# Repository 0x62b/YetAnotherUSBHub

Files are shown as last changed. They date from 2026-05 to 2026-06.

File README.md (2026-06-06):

# YetAnotherUSBHub
A 4-port low cost USB 2.0 hub with upstream USB-C and downstream USB-A x2, USB-C, and microSD.
wip onshape: https://cad.onshape.com/documents/d3076bcf5bdf960a68612e95/w/1076ab7133259d721c6eb065/e/0b541aa8461793eb55190b47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

## Repo Structure
`cad`: CAD files\
`pcb`: The KiCad PCB design files, and gerbers in `pcb/production`\
`bom.csv`: The BOM needed to assemble the PCB\

## BOM
|Item |Unit Price (AUD)|Quantity|Extended Price (AUD)|Extended Price (USD) |Notes |Link |
|---|---|---|---|---|---|---|
|100nF 0402 capacitor |0 |2 |0 |0 |Owned |https://www.lcsc.com/product-detail/C60474.html |
|10uF 0402 capacitor |0 |7 |0 |0 |Owned |https://www.lcsc.com/product-detail/C315248.html |
|onsemi NSR0320MW2T1G |0.16 |10 |1.6 |1.18 |MOQ 10 |https://www.lcsc.com/product-detail/C48192.html |
|Green 0402 LED |0 |1 |0 |0 |Owned |https://www.lcsc.com/product-detail/C598352.html |
|Molex 67643-2911 |1.34 |2 |2.68 |1.92 |N/A |https://www.lcsc.com/product-detail/C293351.html |
|Molex 104031-0811 |1.05 |1 |1.05 |0.75 |N/A |https://www.lcsc.com/product-detail/C585350.html |
|Korean Hroparts Elec TYPE-C-31-M-12|0 |2 |0 |0 |Owned |https://www.lcsc.com/product-detail/C165948.html |
|1K 0402 resistor |0 |1 |0 |0 |Owned |https://www.lcsc.com/product-detail/C106235.html |
|5.1K 0402 resistor |0 |2 |0 |0 |Owned |https://www.lcsc.com/product-detail/C105872.html |
|56K 0402 resistor |0 |2 |0 |0 |Owned |https://www.lcsc.com/product-detail/C114756.html |
|CoreChips SL2.1A |1.65 |1 |1.65 |1.18 |N/A |https://www.lcsc.com/product-detail/C192893.html |
|GENESYS GL823K-HCY04 |0.64 |1 |0.64 |0.46 |N/A |https://www.lcsc.com/product-detail/C284879.html |
|TPD2E2U06DCK |0.21 |3 |1.05 |0.76 |MOQ 5 |https://www.lcsc.com/product-detail/C1855726.html |
|TPD6F003 |0.93 |1 |0.93 |0.67 |N/A |https://www.lcsc.com/product-detail/C2863873.html |
|2mm acrylic sheet |6.25 |1 |6.25 |4.53 |200x200x2mm|https://www.aliexpress.com/item/32817321651.html |
|PCB |- |5 |- |5.3 |N/A |https://jlcpcb.com |

## Cost
BOM (1 board + case): LCSC[6.92 USD + 3 USD handling + 9.38 USD shipping = 19.3 USD] + AliExpress[4.53 USD] = 23.83 USD\
PCB: 2 USD + 3.3 USD shipping = 5.3 USD\
Total: 29.13 USD (1 board + case)

## Assembly
Prerequisites: soldered PCB and printed case (PRINT THE CASE WITH +1-2% SCALE FOR TOLERANCES)

1. Mark out the dimensions of the acrylic window and use a scoring tool to cut it
2. From the sides, glue the acrylic window into the top case
3. Wait for glue to set
4. Place completed PCB into bottom case (optionally, affix it with double sided tape, but it should be held in place by friction anyway
5. Glue the top half onto bottom half (I tried, with this kind of size its not very feasible to use screws or anything)

## Images
### Schematic


### PCB layout


### PCB render


### Full render

The model may appear not to fit, but this was due to the export being messed up. it fits fine according to all my calculations and two braincells

### Zine


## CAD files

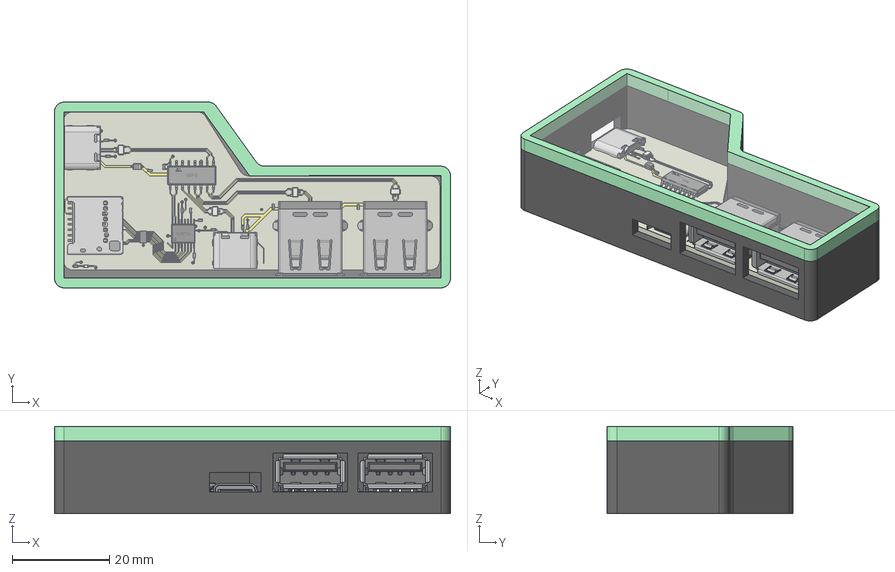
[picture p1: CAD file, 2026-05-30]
cad/usb hub full assembly.step
81.6 x 38.3 x 18.0 mm

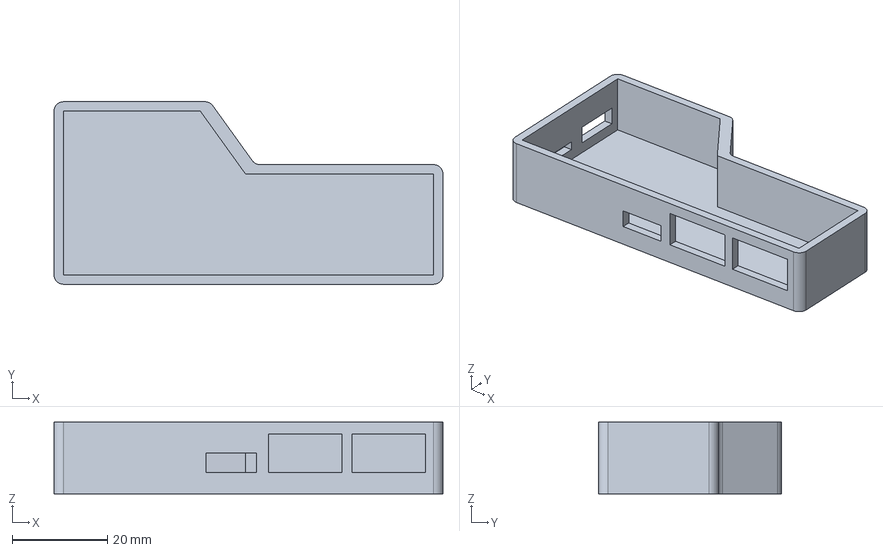
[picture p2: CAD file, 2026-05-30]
cad/usb hub bottom case.step
81.6 x 38.3 x 15.0 mm

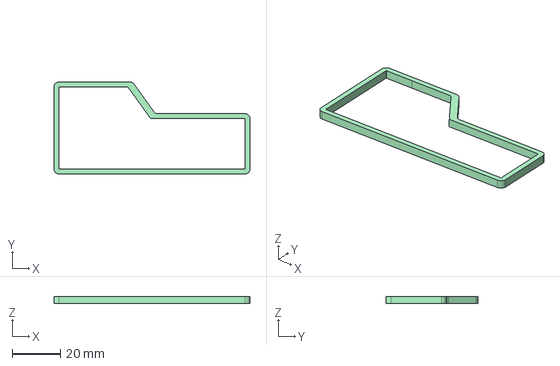
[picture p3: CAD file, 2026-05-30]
cad/usb hub top case.step
81.6 x 38.3 x 3.00 mm

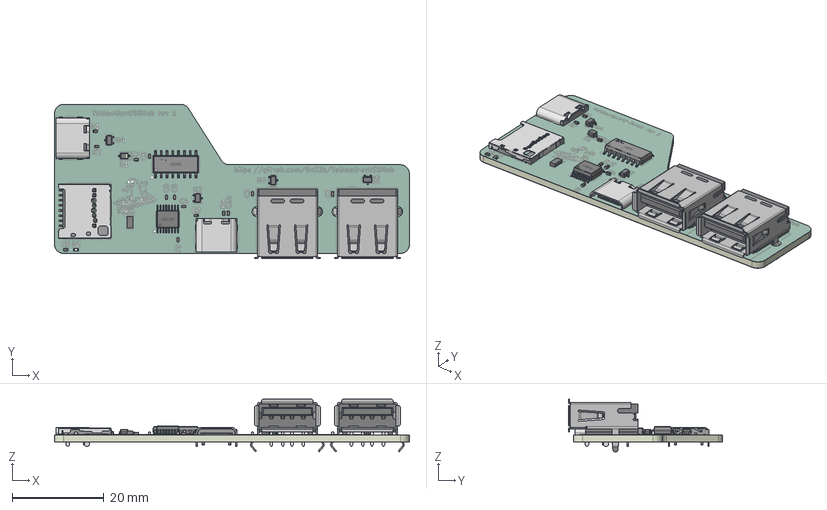
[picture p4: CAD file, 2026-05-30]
cad/board.step
77.6 x 33.7 x 11.5 mm
USB_A_Molex_67643_Horizontal x 2
SOT-323_SC-70 x 4
R_0402_1005Metric x 5
C_0402_1005Metric x 9
SOP-16_L9.9-W3.9-H1.5-LS6.0-P1.27
LED_0402_1005Metric
USB-C-SMD_TYPE-C-6PIN-2MD-073 x 2
D_SOD-323
SSOP-16_L4.9-W3.9-H1.75-LS6.0_P0.64
WSON_12_1EP_135x25mm_P04mm_EP04x2mm
SIM-SMD_8P-1040310811
YetAnotherUSBHub_copper
YetAnotherUSBHub_via
YetAnotherUSBHub_silkscreen
YetAnotherUSBHub_soldermask x 2
YetAnotherUSBHub_PCB

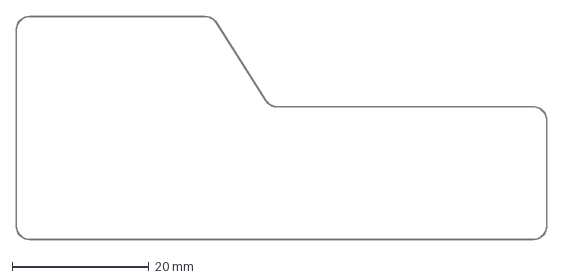
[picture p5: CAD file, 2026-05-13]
cad/YetAnotherUSBHub-Edge_Cuts.dxf
77.7 x 32.7 mm

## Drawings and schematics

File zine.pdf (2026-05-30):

# Yet Another USB Hub

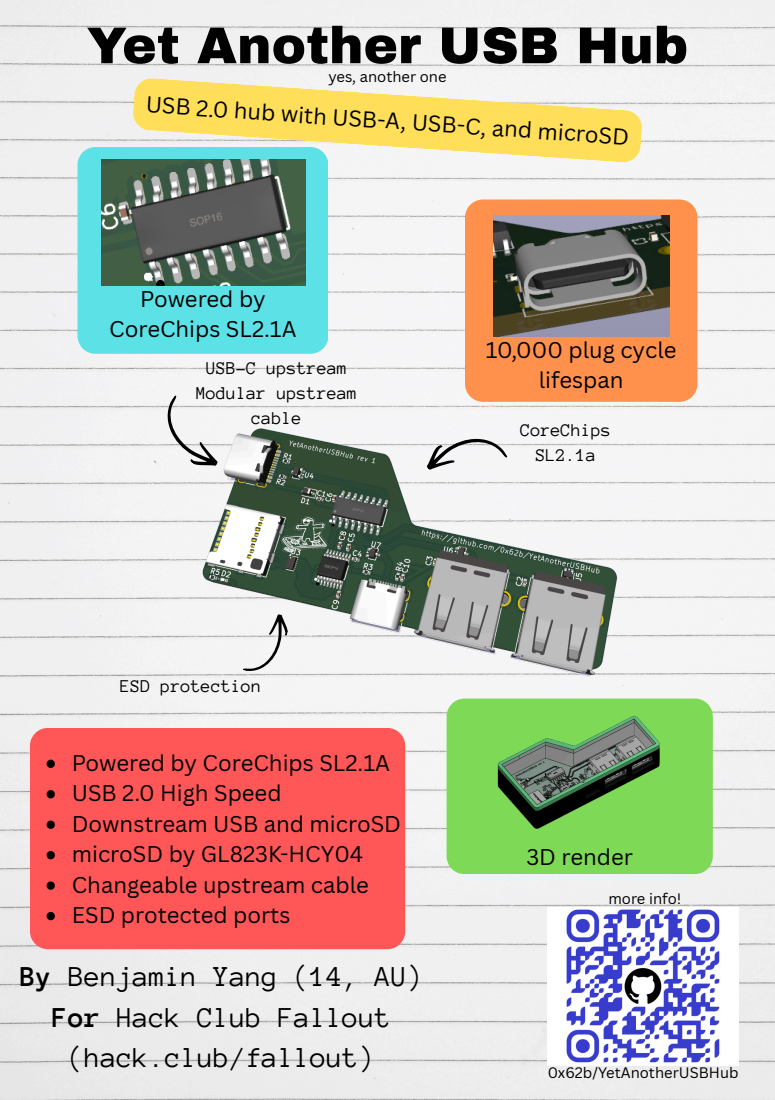
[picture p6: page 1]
Powered by CoreChips SL2.1A; 10,000 plug cycle lifespan; 3D render; USB-C upstream Modular upstream cable; ESD protection; CoreChips SL2.1a

yes, another one

USB 2.0 hub with USB-A, USB-C, and microSD

Powered by CoreChips SL2.1A
USB 2.0 High Speed
Downstream USB and microSD
microSD by GL823K-HCY04
Changeable upstream cable
ESD protected ports

0x62b/YetAnotherUSBHub more info!

By Benjamin Yang (14, AU)
For Hack Club Fallout
(hack.club/fallout)

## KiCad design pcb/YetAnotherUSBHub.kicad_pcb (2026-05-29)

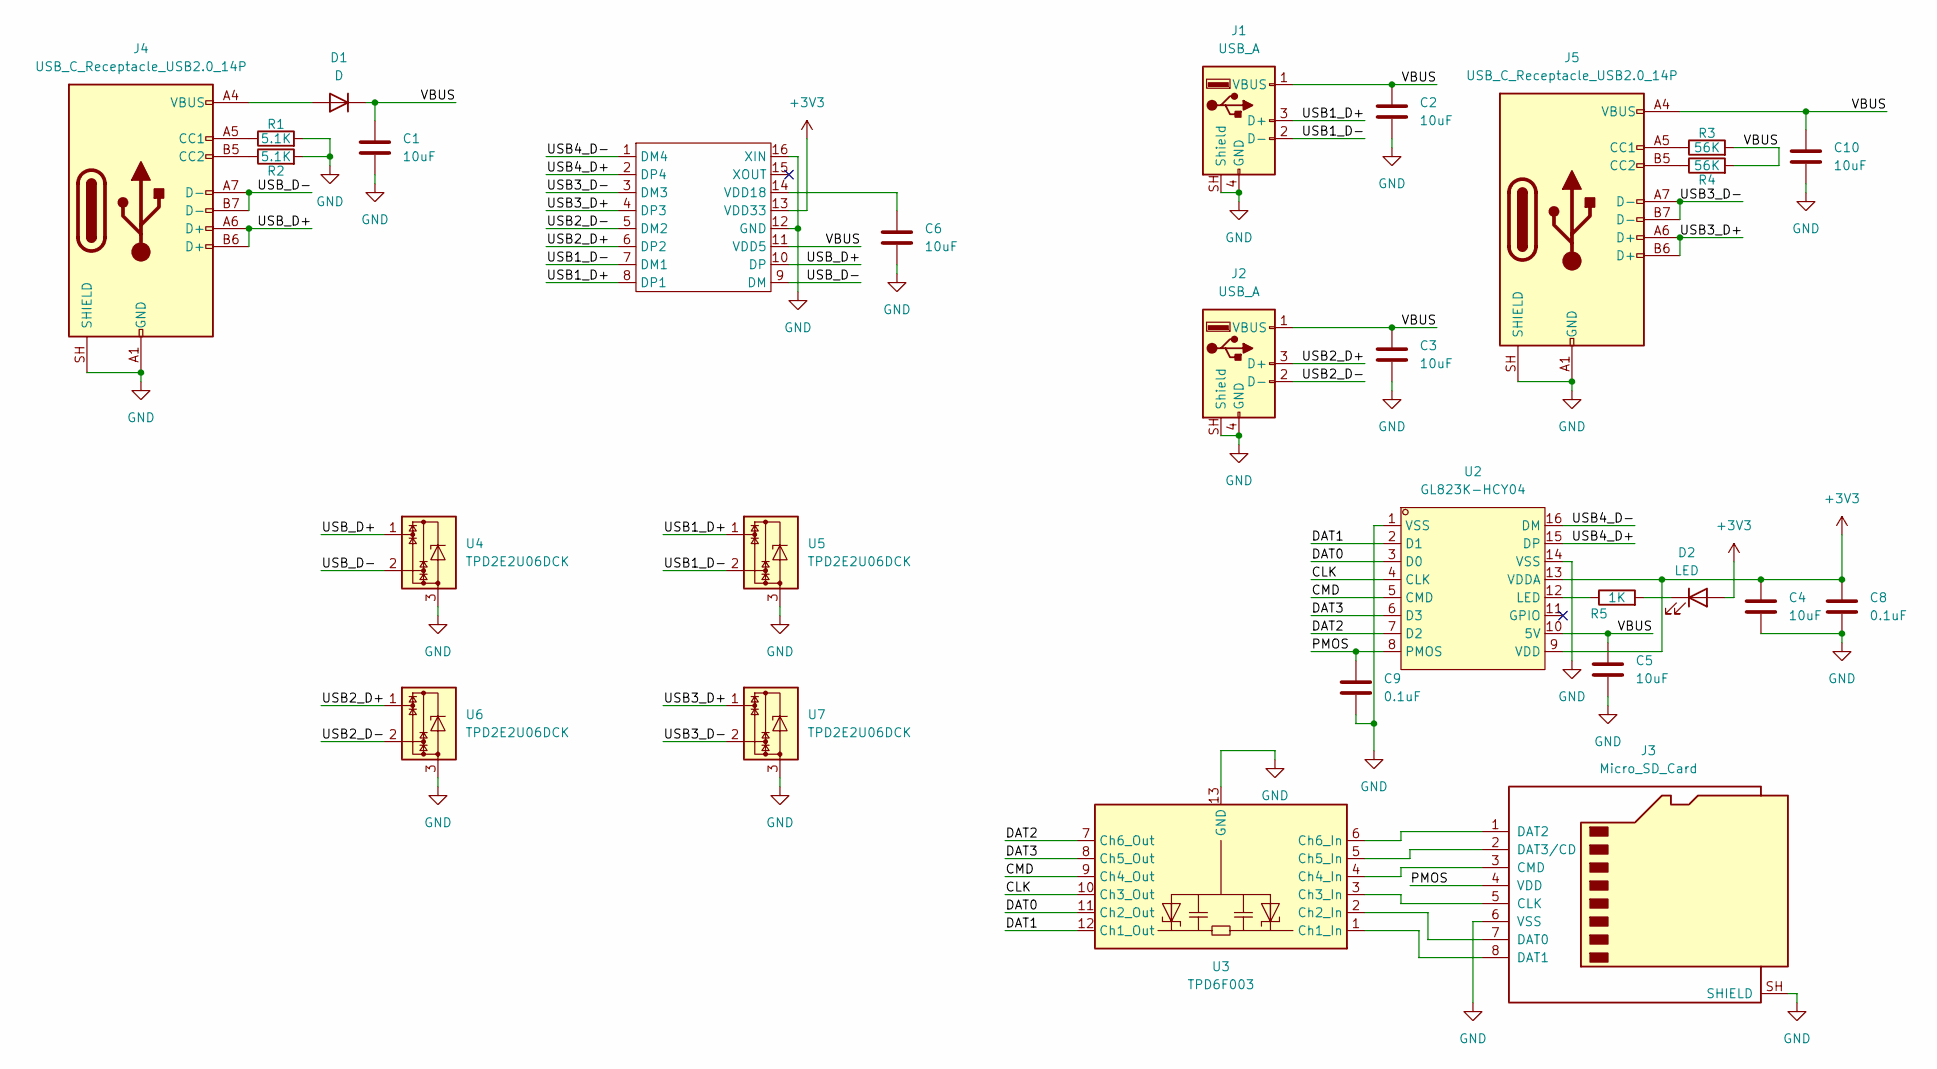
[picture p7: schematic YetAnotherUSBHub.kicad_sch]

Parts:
C1, C2, C3, C4, C5, C6, C10: 10uF; C_0402_1005Metric
C8, C9: 0.1uF; C_0402_1005Metric
D1: D; D_SOD-323
D2: LED; LED_0402_1005Metric
J1, J2: USB_A; USB_A_Molex_67643_Horizontal
J3: Micro_SD_Card; microSD_HC_Molex_104031-0811
J4, J5: USB_C_Receptacle_USB2.0_14P; USB_C_Receptacle_HRO_TYPE-C-31-M-12
R1, R2: 5.1K; R_0402_1005Metric
R3, R4: 56K; R_0402_1005Metric
R5: 1K; R_0402_1005Metric
U1: SOP-16_L10.0-W3.9-P1.27-LS6.0-BL
U2: GL823K-HCY04; SSOP-16_L4.9-W3.9-P0.64-LS6.0-BL; MPN GL823K-HCY04; LCSC Part C284879
U3: TPD6F003; Texas_R-PWSON-N12_EP0.4x2mm
U4, U5, U6, U7: TPD2E2U06DCK; SOT-323_SC-70

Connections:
+3V3: C4.1, C8.1, D2.2 (A), U1.13 (VDD33), U2.9 (VDD), U2.13 (VDDA)
/CLK: U2.4 (CLK), U3.10 (Ch3_Out)
/CMD: U2.5 (CMD), U3.9 (Ch4_Out)
/DAT0: U2.3 (D0), U3.11 (Ch2_Out)
/DAT1: U2.2 (D1), U3.12 (Ch1_Out)
/DAT2: U2.7 (D2), U3.7 (Ch6_Out)
/DAT3: U2.6 (D3), U3.8 (Ch5_Out)
/PMOS: C9.1, J3.4 (VDD), U2.8 (PMOS)
/USB1_D+: J1.3 (D+), U1.8 (DP1), U5.1
/USB1_D-: J1.2 (D-), U1.7 (DM1), U5.2
/USB2_D+: J2.3 (D+), U1.6 (DP2), U6.1
/USB2_D-: J2.2 (D-), U1.5 (DM2), U6.2
/USB3_D+: J5.A6 (D+), J5.B6 (D+), U1.4 (DP3), U7.1
/USB3_D-: J5.A7 (D-), J5.B7 (D-), U1.3 (DM3), U7.2
/USB4_D+: U1.2 (DP4), U2.15 (DP)
/USB4_D-: U1.1 (DM4), U2.16 (DM)
/USB_D+: J4.A6 (D+), J4.B6 (D+), U1.10 (DP), U4.1
/USB_D-: J4.A7 (D-), J4.B7 (D-), U1.9 (DM), U4.2
/VBUS: C1.1, C2.1, C3.1, C5.1, C10.1, D1.1 (K), J1.1 (VBUS), J2.1 (VBUS), J5.A4 (VBUS), J5.A9 (VBUS), J5.B4 (VBUS), J5.B9 (VBUS), R3.2, R4.2, U1.11 (VDD5), U2.10 (5V)
GND: C1.2, C2.2, C3.2, C4.2, C5.2, C6.2, C8.2, C9.2, C10.2, J1.4 (GND), J1.SH (Shield), J2.4 (GND), J2.SH (Shield), J3.6 (VSS), J3.SH (SHIELD), J4.A1 (GND), J4.A12 (GND), J4.B1 (GND), J4.B12 (GND), J4.SH (SHIELD), J5.A1 (GND), J5.A12 (GND), J5.B1 (GND), J5.B12 (GND), J5.SH (SHIELD), R1.2, R2.2, U1.12 (GND), U1.16 (XIN), U2.1 (VSS), U2.14 (VSS), U3.13 (GND), U4.3, U5.3, U6.3, U7.3
unnamed: D1.2 (A), J4.A4 (VBUS), J4.A9 (VBUS), J4.B4 (VBUS), J4.B9 (VBUS)
unnamed: D2.1 (K), R5.2
unnamed: J3.5 (CLK), U3.3 (Ch3_In)
unnamed: J3.3 (CMD), U3.4 (Ch4_In)
unnamed: J3.7 (DAT0), U3.2 (Ch2_In)
unnamed: J3.8 (DAT1), U3.1 (Ch1_In)
unnamed: J3.1 (DAT2), U3.6 (Ch6_In)
unnamed: J3.2 (DAT3/CD), U3.5 (Ch5_In)
unnamed: J4.A5 (CC1), R1.1
unnamed: J4.B5 (CC2), R2.1
unnamed: J5.A5 (CC1), R3.1
unnamed: J5.B5 (CC2), R4.1
unnamed: C6.1, U1.14 (VDD18)
unnamed: R5.1, U2.12 (LED)

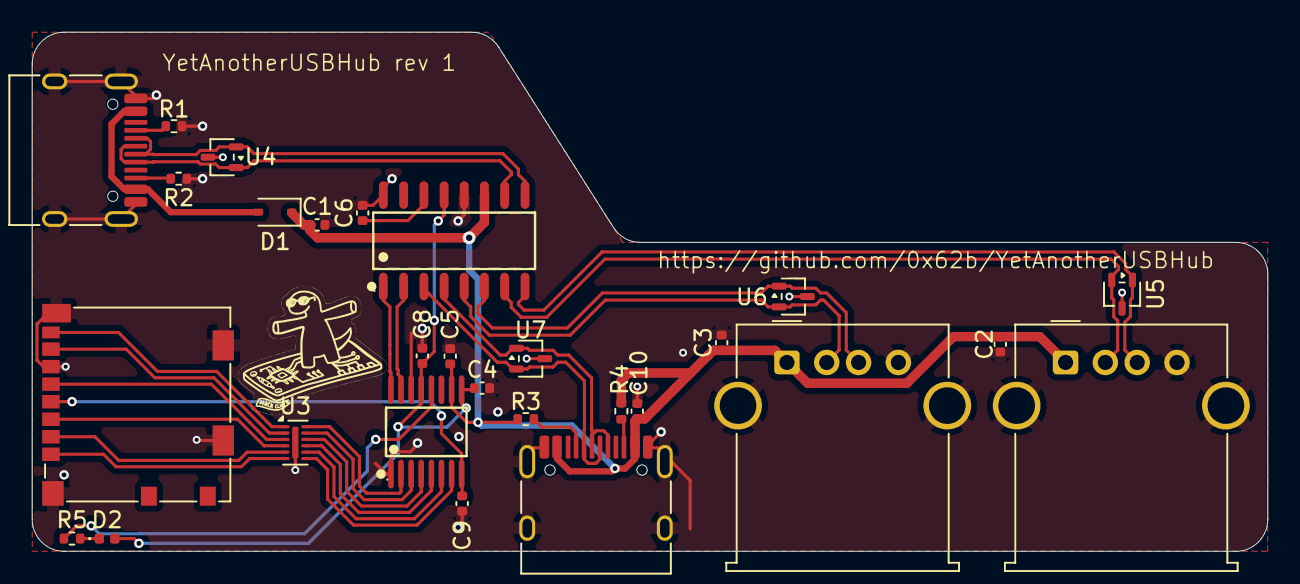
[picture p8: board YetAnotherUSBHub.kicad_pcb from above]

Board: 2 copper layers, 77.6 x 32.6 mm, 28 parts (0 on the bottom side), 34 nets.

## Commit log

2026-05-13 cad files
    [YetAnotherUSBHub-Edge_Cuts.dxf, usb hub bottom case.step, usb hub top case.step]
2026-05-13 add assembly instructions, add case hardware to bom
    [bom.csv]
2026-05-29 new bom
    [bom.csv]
2026-05-29 esd protection on pcb
    [YetAnotherUSBHub.kicad_pcb, YetAnotherUSBHub.kicad_sch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]
2026-05-29 Remove lcsc.csv
    [lcsc.csv]
2026-05-30 new board export
    [board.step]
2026-05-30 update case cad files
    [usb hub bottom case.step, usb hub full assembly.step, usb hub top case.step]
